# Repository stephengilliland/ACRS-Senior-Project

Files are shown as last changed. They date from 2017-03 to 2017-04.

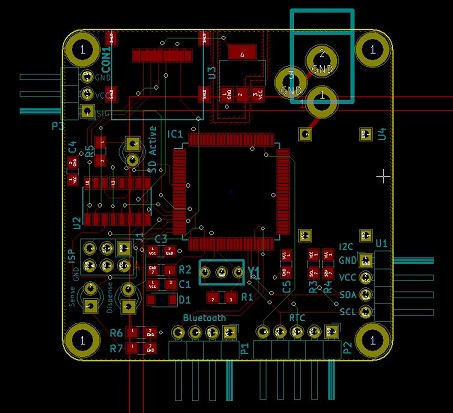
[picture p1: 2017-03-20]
Boards/SP1/BoardLayoutPIC.JPG

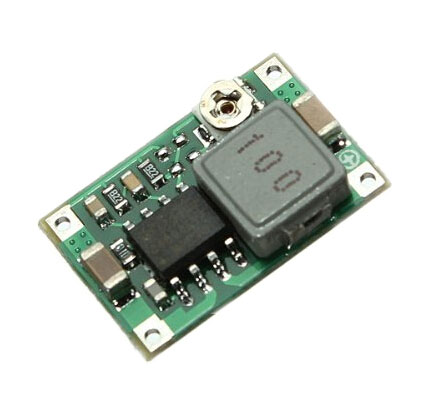
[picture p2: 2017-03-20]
Boards/SP1/Buck.jpg

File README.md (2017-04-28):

# Aquatic Chemical Regulation System (ACRS)

#### Group Members:
- Stephen Gilliland
- Nicholas Zugates
- George Tittnitch

## What is ACRS?
ACRS is a water chemical regulation system which uses various sensors connected via I2C bus to take measurements of chemical content, temperature, pH and turbidity. These readings are used in order to make adjustments to the balance of chemicals in the water. The system is interfaced to the user via an Android app. The readings aquired by the system are logged in a microSD card for recordkeeping purposes.

The main goal of the system is modularity; meaning any of our sensors connected to the controller I2C bus will be automatically recognized and read. The I2C bus is compatible with up to 127 slave devices.

## Hardware

The project utilizes multiple microprocessors, one of which acts as a I2C Master(Main Controller), the rest are attached to the sensors and act as Slave devices(Sensors). The master is a different processor due to the need of more program space. The other device's programs are minimal thus they do not need much space.

Device | MicroController Used | Program Space | SRAM
------------ | ------------- | ------- | ----- 
Master device | ATmega2560 | 256KB | 8KB
Slave devices | ATmega328 | 32KB | 2KB

## Software
The software for the main controller is an large part of ACRS due to the many functions of the diverse system and the number of sensors that can be used with it.  Some of the functions include: Reading sensors, app communication, timekeeping, data logging, and pump control. Due to the ability to customize these things from the app, the program is extensive.

The initial setup of the program initializes variables, outputs, and some of the devices hooked up to the controller. It also sets up the bluetooth parameters. It then searches for connected sensors by testing every possible I2C address (1 to 128, 0 is the controller) and saving the addresses of the devices connected into an array. The array is used to increment through all sensor’s addresses and get their values. This is done by requesting 2 bytes, the first is the sensor type and the second is the data from that sensor. The controller then saves the data into the correct variable based on what sensor was just read. This process is done for every sensor connected every time the program runs the read sensors function. 

The main loop of the program works in response to commands received from the smartphone app, these commands trigger specific actions in the controller such as: setting user settings or sending data to the app. The commands are sent as 1 character numbers and interpreted by the controller. There are 6 different commands the controller can receive from the app, they are as follows:

Set dispense mode: Automatic
Set dispense mode: Manual
Get Sensor readings
Dispense chemicals (if set to manual)
Change pool size
Change measurement interval

Changing the dispense mode to automatic simply changes the controller mode to dispense chemicals on it’s own when the readings are out of a preset tolerance. While when set to manual mode, the controller will not do anything until the user sends the command to do so.

A command to get new sensor readings makes the controller send the most recent measurements. As soon is this request is made, a string is sent over bluetooth containing the sensor values. The string is parsed and the values are displayed by the app. 

A dispense chemicals command causes the controller to make calculations based on the user entered pool size, chemical measurements, and desired chemical content. It then sends data to the dispensing controller which takes the necessary action in order to regulate the chemical content of the water. This command is only used if the dispensing setting is set to manual.

The last two commands simply set some preferences. Set pool size sets the size of the body of water being regulated, this is important due to the calculations that are done before dispensing chemicals being dependant on this data. The second preference is the test interval, this preference is the amount of time (in minutes) between each chemical test, because data is logged every time sensor readings are gathered; this also sets the data logging interval.

### The Controller
The device chosen for this for the main controller is the Atmega2560. The Atmega2560 is an 8-bit microcontroller that is well suited for the application. There are many reasons that this controller was the right one for the application: it’s an Arduino compatible processor, it has the serial peripherals needed to communicate to the necessary devices, and it has enough memory space to hold the large main program. 

Arduino compatibility is a very beneficial advantage due to the large amount of libraries and support that are available. Arduino also has a very convenient windows application for writing code, compilation, and uploading. The controller also needed a number of serial peripherals in order to communicate to the necessary devices such as: UART for communication to the bluetooth chip (RN-42) , I2C in order to get sensor values, and SPI to write to the microSD card for data logging purposes.

Because of the large number of devices the controller needed to interface with, a PCB was created which contains most of the needed devices and supporting circuitry. Included in the controller PCB are: the controller (Atmega2560), voltage regulators (3.3V and 5V), a microSD slot with supporting level-translators, and a 12DC input power jack.



### Data Logging
Data is logged to a microSD card using the SPI interface of the Atmega2560, with every set of values that are logged, a timestamp is also logged in order to give the user a record of data along with the date and time of the measurements.  An example of a data entry is as follows: 

“4/23/2017 20:23:59  pH=7.1  Temp=71.23  Chlorine=2.23  Trepidity=95”

### Sensors
The system begins with the three modular sensors collecting data from the water that is pulled through the system. These sensors each have a dedicated microcontroller that continually take measurements of the sensor values and send these values to the main controller upon request. The first sensor that the water passes over is the chlorine sensor. The design of the chlorine sensor is as followed. The base for the sensor is the TSL235R-LF light intensity to frequency converter. Its purpose is to collect light within the enclosure into which the water will be pumped. The light source is for the sensor is an LED that is mounted in a tube in order to direct the light through the water directly onto the sensors photodiode. The other key element in making this sensor work is the DPD chemical that is added through the top of the sensors container. This substance changes the color of the water to a purple hugh based off of the amount of free chlorine present in it. Now, once the DPD is added and the water changes color, the purple color blocks some of the light to the sensor. So, in order for this sensor to give relevant data, a correlation between the outputted frequency and the amount of chlorine needed to be made. This was done by utilizing the pool test kit described earlier. A sample of water was taken from the source and used in the pool test kit which would give a value between 1 and 5 parts per million. At the same time the same water source that the sample for the pool test kit was taken from was run through the sensor and the DPD was applied. Thus, the frequency that was outputted would correlate with the results given from the pool test kit (10KHZ = 2ppm for example).  
    
The pH sensor works similar to an amperometric sensor listed above. The main difference being that there is a plastic shield over the electrodes. The sensor compares the water passing over it to a controlled water sample stored in the sensor. The sensor outputs an analog signal that correlates to the pH level. This was done by using a sample of distilled water and adding pH packets  that were provided with the sensor. These packets, when mixed with distilled water, create a solution of known pH level. This was how the sensor calibration was performed. An example of this would be if a pH 4 packet was added whatever analog signal was outputted is the signal for a pH of 4. 

Finally, the turbidity sensor senses the clearness of the water. This a key test in water quality and even though it does not necessarily fit into the proof of concept, it is a perfect example of how the The A.C.R.S. is adaptable to multiple scenarios. The same goes for the temperature sensor, they are simply helpful for the user to have and show the future possibilities of the project. 

### The App
In order to give the user the most personal experience with the A.C.R.S. system, a user interface was developed in the form of an Android application.  This medium was chosen because in the current day and age it is most convenient for the everyday pool owner.  The app is easy to download, sync to the main system via Bluetooth, control, and monitor.

There are many programs on the market that can be used for Android application development. After experimentation with Android Studio, it was decided that another option was needed.  Further research concluded that MIT App Inventor 2 was the best option for the A.C.R.S. project purposes.

Upon further development the application could be altered and formatted for tablets and other personal devices.  As of now, the application is designed specifically for smartphones.

## Pictures/Videos
Put pictures and videos here.

## Resumes
- [Stephen Gilliland](./Resumes/SGilliland_Resume.pdf)
- [Nicholas Zugates](./Resumes/N_ZugatesResume.pdf)
- [George Tittnich](./Resumes/GeorgeTittnich_Resume.pdf )

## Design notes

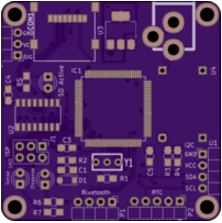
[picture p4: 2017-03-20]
Boards/SP1/Image.JPG

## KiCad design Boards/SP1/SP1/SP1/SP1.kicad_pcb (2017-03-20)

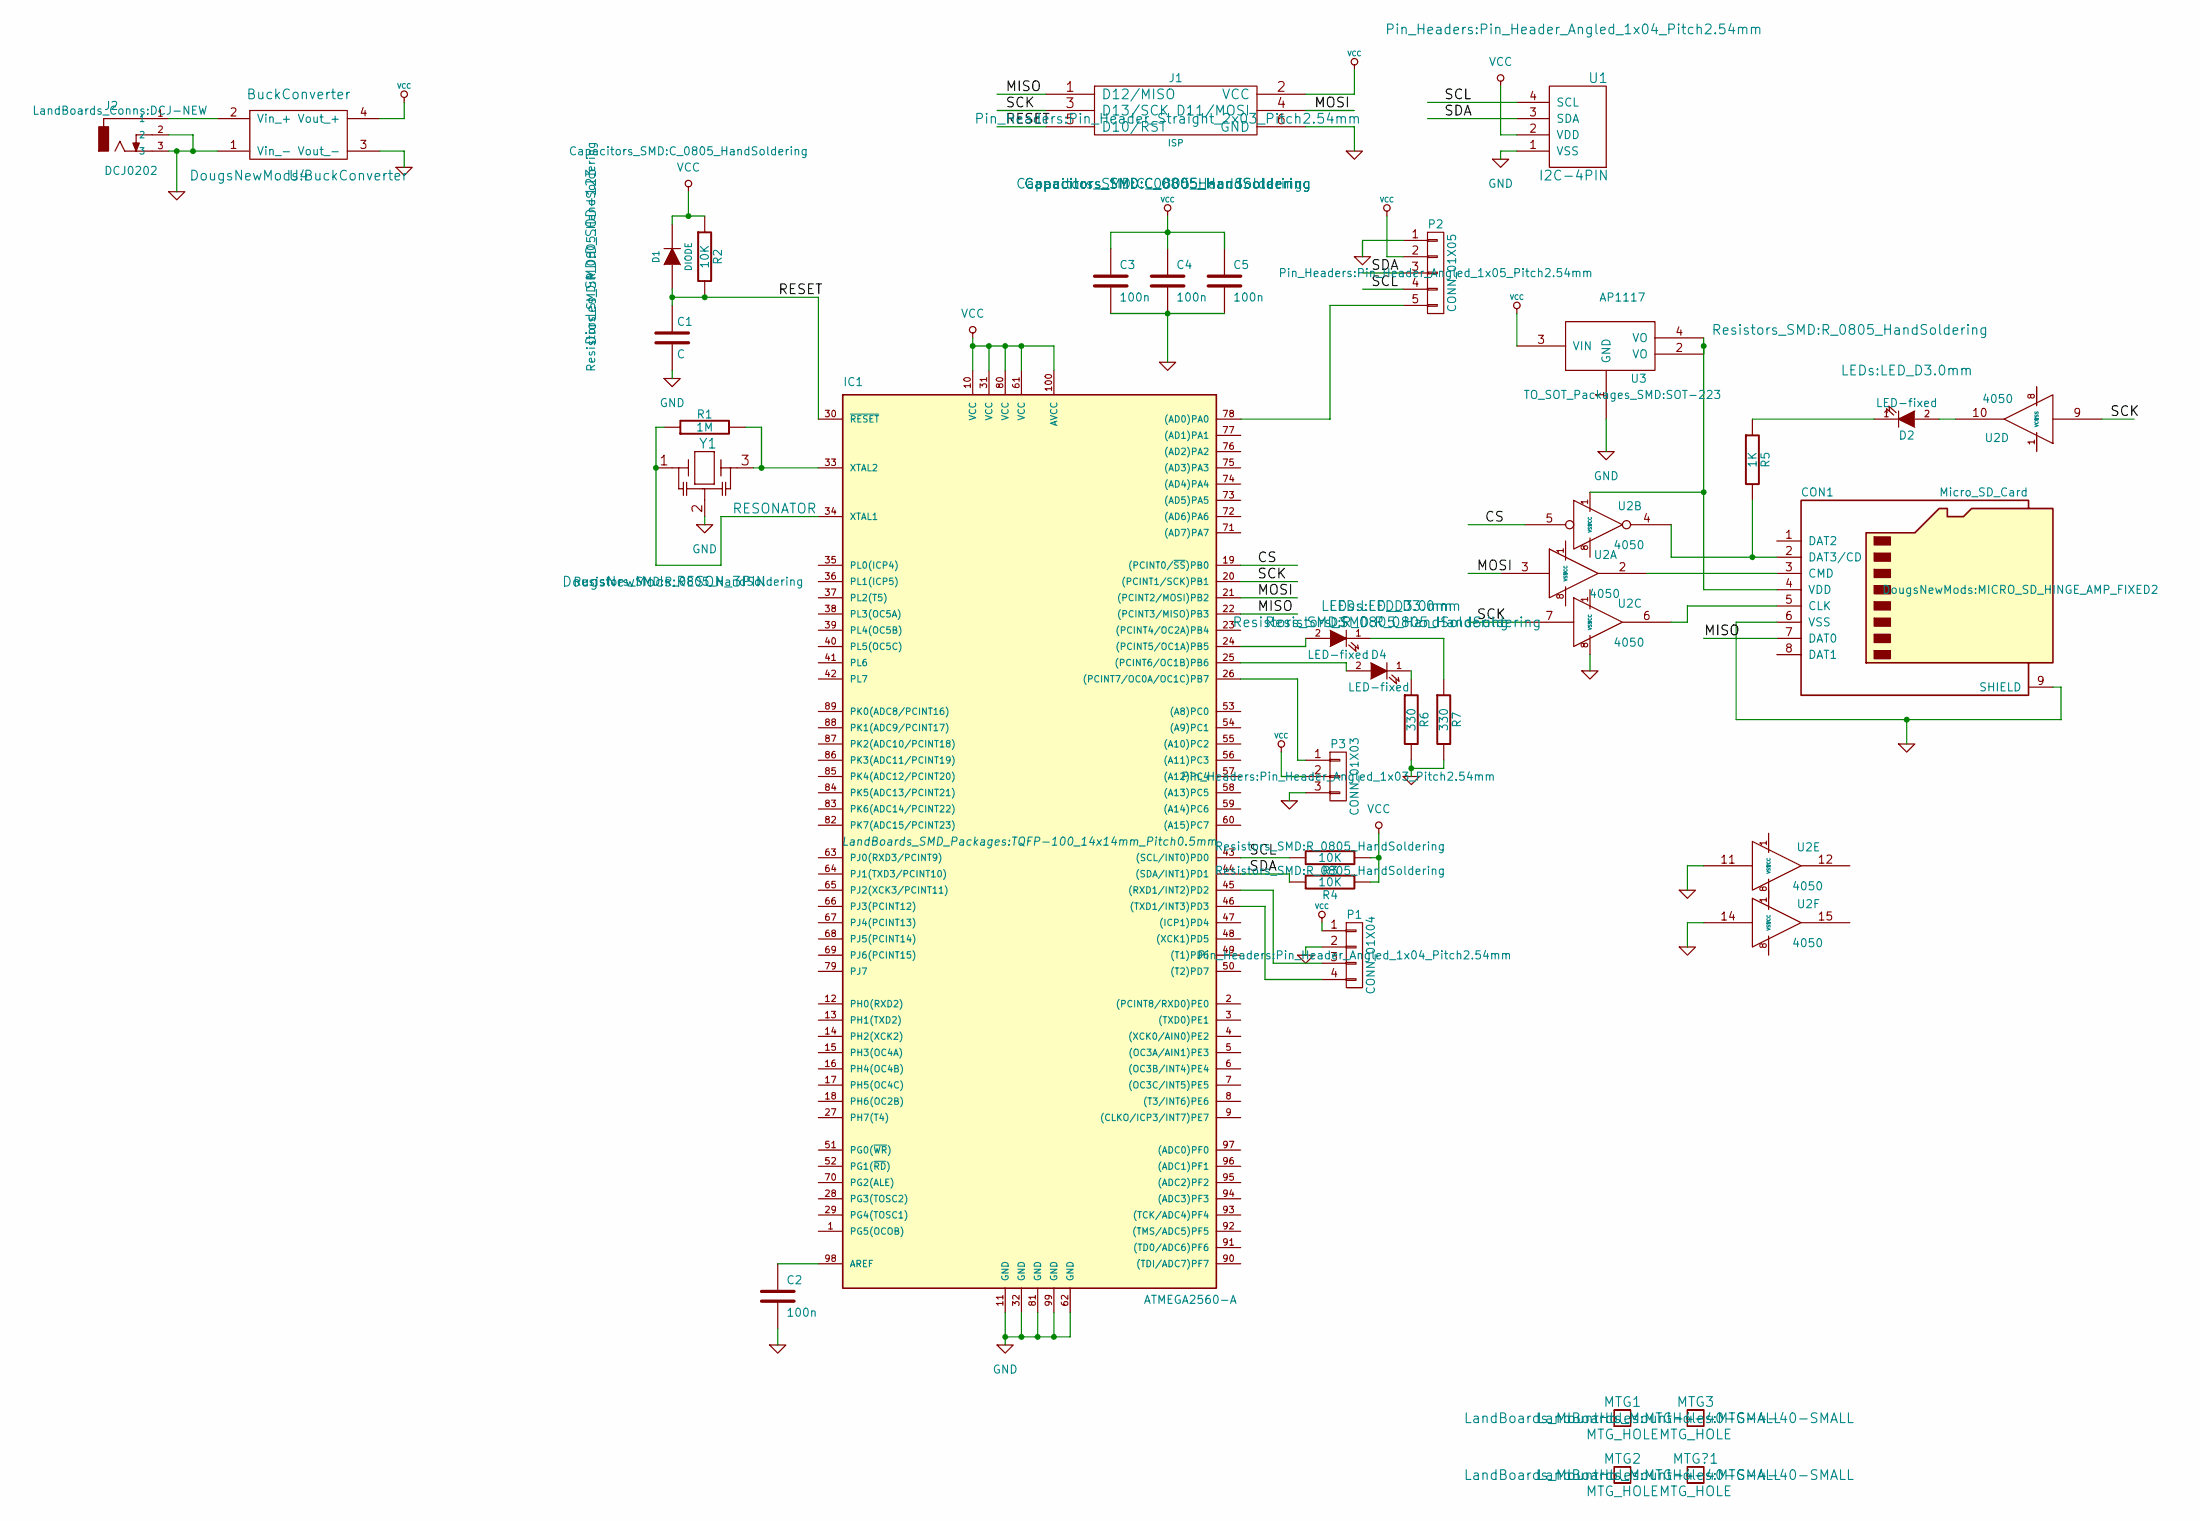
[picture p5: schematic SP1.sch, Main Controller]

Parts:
C1: C; C_0805_HandSoldering
C2: 100n
C3, C4, C5: 100n; C_0805_HandSoldering
CON1: Micro_SD_Card; MICRO_SD_HINGE_AMP_FIXED2
D1: DIODE; D_SOD-123
D2, D3, D4: LED-fixed; LED_D3.0mm
IC1: ATMEGA2560-A; TQFP-100_14x14mm_Pitch0.5mm
J1: ISP; Pin_Header_Straight_2x03_Pitch2.54mm
J2: DCJ0202; DCJ-NEW
MTG1, MTG2, MTG3: MTG_HOLE; MTG-4-40-SMALL
MTG?1: MTG_HOLE; MTG-4-40-SMALL
P1: CONN_01X04; Pin_Header_Angled_1x04_Pitch2.54mm
P2: CONN_01X05; Pin_Header_Angled_1x05_Pitch2.54mm
P3: CONN_01X03; Pin_Header_Angled_1x03_Pitch2.54mm
R1: 1M; R_0805_HandSoldering
R2, R3, R4: 10K; R_0805_HandSoldering
R5: 1K; R_0805_HandSoldering
R6, R7: 330; R_0805_HandSoldering
U1: I2C-4PIN; Pin_Header_Angled_1x04_Pitch2.54mm
U2: 4050; SOIC-16_3.9x9.9mm_Pitch1.27mm
U3: AP1117; SOT-223
U4: BuckConverter
Y1: RESONATOR; RESON_3PIN

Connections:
/CS: IC1.19 ((PCINT0/~SS~)PB0), U2.5
/MISO: CON1.7 (DAT0), IC1.22 ((PCINT3/MISO)PB3), J1.1 (D12/MISO)
/MOSI: IC1.21 ((PCINT2/MOSI)PB2), J1.4 (D11/MOSI), U2.3
/RESET: C1.1, D1.1 (A), IC1.30 (~RESET), J1.5 (D10/RST), R2.2
/SCK: IC1.20 ((PCINT1/SCK)PB1), J1.3 (D13/SCK), U2.7, U2.9
/SCL: IC1.43 ((SCL/INT0)PD0), P2.4, R3.2, U1.4 (SCL)
/SDA: IC1.44 ((SDA/INT1)PD1), P2.3, R4.2, U1.3 (SDA)
GND: C1.2, C2.2, C3.2, C4.2, C5.2, CON1.6 (VSS), CON1.9 (SHIELD), IC1.11 (GND), IC1.32 (GND), IC1.62 (GND), IC1.81 (GND), IC1.99 (GND), J1.6 (GND), J2.2, J2.3, P1.2, P2.1, P3.3, R6.2, R7.2, U1.1 (VSS), U2.8 (VSS), U2.11, U2.14, U3.1 (GND), U4.1 (Vin_-), U4.3 (Vout_-), Y1.2
unnamed: C2.1, IC1.98 (AREF)
unnamed: CON1.2 (DAT3/CD), R5.2, U2.4
unnamed: CON1.3 (CMD), U2.2
unnamed: CON1.4 (VDD), U2.1 (VCC), U3.2 (VO), U3.4 (VO)
unnamed: CON1.5 (CLK), U2.6
unnamed: D2.1 (K), R5.1
unnamed: D2.2 (A), U2.10
unnamed: D3.1 (K), R7.1
unnamed: D3.2 (A), IC1.24 ((PCINT5/OC1A)PB5)
unnamed: D4.1 (K), R6.1
unnamed: D4.2 (A), IC1.25 ((PCINT6/OC1B)PB6)
unnamed: IC1.26 ((PCINT7/OC0A/OC1C)PB7), P3.1
unnamed: IC1.33 (XTAL2), R1.2, Y1.3
unnamed: IC1.34 (XTAL1), R1.1, Y1.1
unnamed: IC1.45 ((RXD1/INT2)PD2), P1.3
unnamed: IC1.46 ((TXD1/INT3)PD3), P1.4
unnamed: IC1.78 ((AD0)PA0), P2.5
unnamed: J2.1, U4.2 (Vin_+)
VCC: C3.1, C4.1, C5.1, D1.2 (K), IC1.10 (VCC), IC1.31 (VCC), IC1.61 (VCC), IC1.80 (VCC), IC1.100 (AVCC), J1.2 (VCC), P1.1, P2.2, P3.2, R2.1, R3.1, R4.1, U1.2 (VDD), U3.3 (VIN), U4.4 (Vout_+)

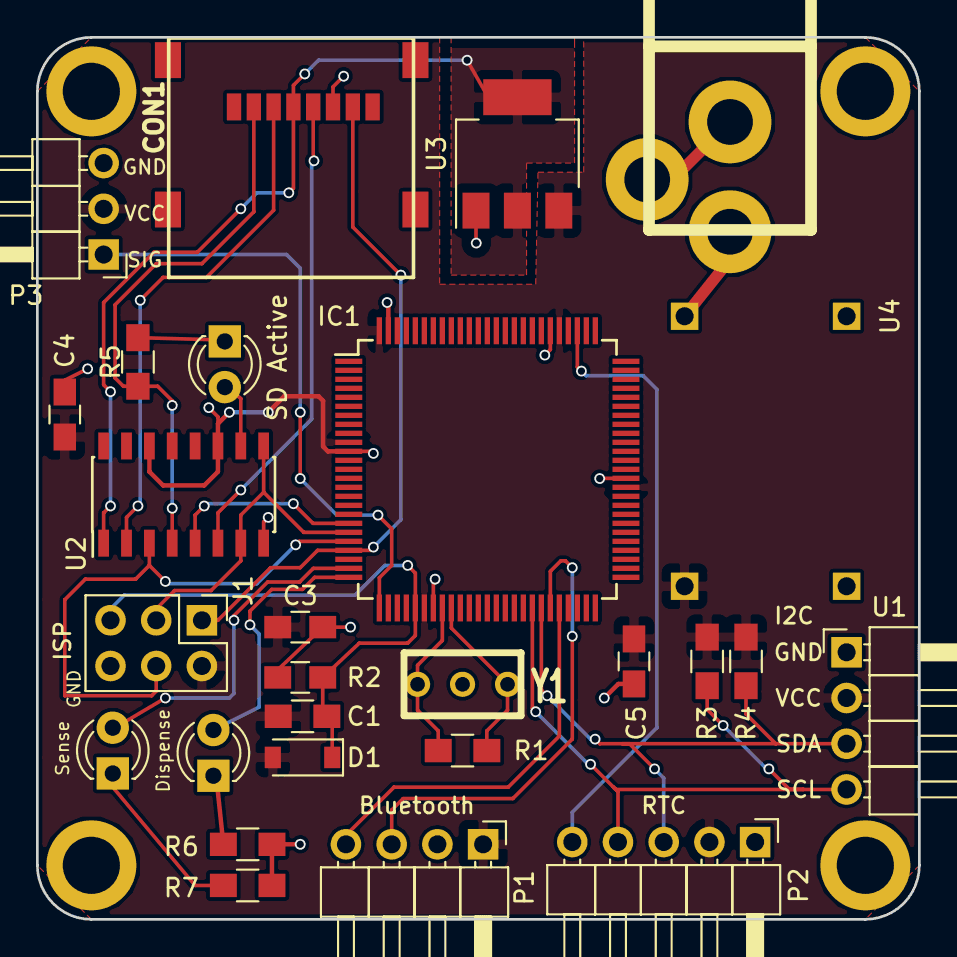
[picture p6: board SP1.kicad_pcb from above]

Board: 2 copper layers, 49.0 x 49.0 mm, 31 parts (0 on the bottom side), 26 nets.

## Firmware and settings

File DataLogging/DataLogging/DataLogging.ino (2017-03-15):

//Time stamped datalogger onto SD Card 
//@vmfoo - 7/19/2014

// change this to match your SD shield or module;
// Arduino Ethernet shield: pin 4
// Adafruit SD shields and modules: pin 10
// Sparkfun SD shield: pin 8
const int chipSelect = 4;    
//The RTC Library needs Wire
#include <Wire.h>
#include "RTClib.h"
RTC_DS1307 rtc;

#include <SPI.h>
#include "SD.h"
//The SDlibrary needs SPI

// Some SD Card code borrowed from Adafruit library examples
// Set up variables using the SD utility library functions:

File dataFile;
#define LOGFILE "datalog.txt"



void setup() {
  Serial.begin(19200); 
  //Initialize the Sensor
  Serial.println("Initializing datalogger with RTC version 1.0");
  
  
  Serial.println("Starting SDCard reader and card");
  pinMode(chipSelect, OUTPUT);
  pinMode(SS, OUTPUT);
  
  if (!SD.begin(chipSelect)) {
    Serial.println("SD Card initialization failed!");
    return;
  }
  
  Serial.println("Opening logfile for write.");
  // Open up the file we're going to log to!
  dataFile = SD.open(LOGFILE, FILE_WRITE);
  if (! dataFile) {
    Serial.println("error opening log file");
    // Wait forever since we cant write data
    while (1) ;
  }
  
  
  Serial.println("Starting Real Time Clock");
  #ifdef AVR
    Wire.begin();
  #else
    Wire1.begin(); // Shield I2C pins connect to alt I2C bus on Arduino Due
  #endif

  rtc.begin();
  //rtc.adjust(DateTime(F(__DATE__), F(__TIME__)));  //uncomment this once and upload. Then comment it out and upload again
  //This will set the time the first time you upload it and if you don't upload again with it commented out it will 
  //reset the clock to the time the code was compliled each time.
  
  if (! rtc.isrunning()) {  //code borrowed from adafruit example rtc code
    Serial.println("RTC is NOT running!");
    // following line sets the RTC to the date & time this sketch was compiled
    // This line sets the RTC with an explicit date & time, for example to set
    // January 21, 2014 at 3am you would call:
    // rtc.adjust(DateTime(2014, 1, 21, 3, 0, 0));
  }
  DateTime now = rtc.now();
  Serial.print("Unixtime: ");
  Serial.println(now.unixtime());
}

void loop(){
  char temp[6]; //2 int, 2 dec, 1 point, and \0
  char hum[6];  
  char msg[13];
  
  //get the temp/humid into chars to format
  ftoa(temp,20);
  ftoa(hum,55);
  
  //Compile a comma delimited string to send to the log
  sprintf(msg,"%s,%s",temp, hum);
  logThis(msg);  
  delay(3000); 
}

void logThis(char* logmessage){
  char message[120];
  DateTime now = rtc.now();
  long epoch = now.unixtime();
  int Year = now.year();
  int Month = now.month();
  int Day = now.day();
  int Hour = now.hour();
  int Minute = now.minute();
  int Second = now.second();
  sprintf(message, "%ld,%d/%d/%d %02d:%02d:%02d,%s",epoch,Year,Month,Day,Hour,Minute,Second,logmessage );
  //Write the entry to the log file and console
  dataFile.println(message);
  dataFile.flush();
  // print to the serial port too:
  Serial.println(message);
}

int ftoa(char *a, float f)  //translates floating point readings into strings
{
  int left=int(f);
  float decimal = f-left;
  int right = decimal *100; //2 decimal points
  if (right > 10) {  //if the decimal has two places already. Otherwise
    sprintf(a, "%d.%d",left,right);
  } else { 
    sprintf(a, "%d.0%d",left,right); //pad with a leading 0
  }
}

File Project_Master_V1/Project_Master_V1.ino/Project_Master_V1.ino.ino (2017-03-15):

const int chipSelect = 4; 
#include "TinyGPS.h"
#include<SoftwareSerial.h>
#include <Wire.h>
#include <SPI.h>
#include "SD.h"

#define RXPIN 8
#define TXPIN 7
#define LOGFILE "datalog.txt"

SoftwareSerial nss(RXPIN, TXPIN);
File dataFile;
TinyGPS gps;



int x, i, error, data, ndevices, counter, current, requestdata = 0;
float PH, AL, TR, TP, CH = 0;
unsigned long fix_age, Time, date;
unsigned long chars;
unsigned short sentences, failed_checksum;
char sensortype = '0';
int device[10];
bool done=false;

void setup() {
  // put your setup code here, to run once:
  nss.begin(9600);
  
  Wire.begin(); 
  
  Serial.begin(9600);
  while(!Serial){}
  Serial.print("$$$");
  delay(100);
  Serial.println("SM,0");
  delay(100);
  Serial.println("U,115200,N");
  delay(100);
  Serial.begin(9600);
  delay(100);

  Serial.println("Initializing datalogger");
  Serial.println("Starting SDCard");
  pinMode(chipSelect, OUTPUT);
  pinMode(SS, OUTPUT);
  
  if (!SD.begin(chipSelect)) {
    Serial.println("SD Card initialization failed!");
    return;
  }
  
  Serial.println("Opening logfile for write.");
  // Open up the file we're going to log to!
  dataFile = SD.open("datalog.txt", FILE_WRITE);
  if (! dataFile) {
    Serial.println("error opening log file");
    // Wait forever since we cant write data
    while (1) ;
  }
  dataFile.close();
  
  // Discover Devices
  for( i=1; i<128; i++ )
  {
    Wire.beginTransmission(i);
    error = Wire.endTransmission();
    if(error == 0)
    {
      ndevices ++;
    }
  }
  device[ndevices];
  
  // Discover Devices
  for(i=1; i<127; i++)
  {
    Wire.beginTransmission(i);
    error = Wire.endTransmission();
    if(error == 0)
    {
      device[counter] = i;
      counter++;
    }
  }
  Serial.print(ndevices);
  Serial.println(" Devices Found At Addresses: ");
  for( i=0;i<ndevices;i++ )
  {
    Serial.println(device[i]);  
  }
  Serial.println(" ");
}

void loop() {
  // put your main code here, to run repeatedly: 
   
  char tempS[7]; //2 int, 2 dec, 1 point, and \0
  char phS[7]; 
  char tripS[7];
  char chlorineS[7]; 
  char alkS[7];
  char msg[25];
  i = 0;
  counter = 0;
  
  while(done==false && counter<100)
  {
    while (nss.available())
    {
      int c = nss.read();
      if (gps.encode(c))
      {
        // process new gps info here
      }
    }  
    delay(10);
    // time in hhmmsscc, date in ddmmyy
    gps.get_datetime(&date, &Time, &fix_age);
    //Serial.println("Date/Time:");
    //Serial.println(Time);
    //Serial.println(date); 
    //Serial.println(counter); 
    counter++; 
  }
  done=true;

  // Get GPS Data
  while (nss.available())
  {
    int c = nss.read();
    if (gps.encode(c))
    {
      // process new gps info here
    }
  }  

  // Read Device Info
  for( i=0;i<ndevices;i++ )
  {
    Serial.print("Loop Number:  ");
    Serial.println(i);
    current = device[i];
    
    Wire.requestFrom(current, 1);    // request 1 byte from slave devices
    while (Wire.available())   // slave may send less than requested
    {
      sensortype = (char)Wire.read(); // receive a byte as character
    }

    Wire.requestFrom(current, 1);    // request 1 byte from slave devices
    while (Wire.available())   // slave may send less than requested
    {
      data = Wire.read(); // receive a byte as character
    }

    
    if(sensortype == 'P') // pH Sensor
    {
      PH = (float) data/10;
      Serial.print("Sensor Type = ");
      Serial.println("pH");
      Serial.print("pH = ");
      Serial.println(PH);
      Serial.println(" ");
    }
    if(sensortype == 'T') // Tribitiy Sensor
    {
      TR = data;
    }
    if(sensortype == 'A') // pH Sensor
    {
      AL = data;
      Serial.print("Sensor Type = ");
      Serial.println("Alkalenity");
      Serial.print("Alk = ");
      Serial.println(AL);
      Serial.println(" ");
    }
    if(sensortype == 'F') // pH Sensor
    {
      TP = data;
      Serial.print("Sensor Type = ");
      Serial.println("Temperature");
      Serial.print("temperature = ");
      Serial.println(TP);
      Serial.println(" ");
    }

   
  } 
  
   Serial.println("Done Looping");

   Serial.println(TP);
   Serial.println(PH);
   Serial.println(AL);
   Serial.println(CH);
   ftoa(tempS,TP);
   ftoa(phS,PH);
   ftoa(tripS,TR);
   ftoa(chlorineS,CH);
   
   sprintf(msg,"%s,%s,%s,%s",tempS, phS, tripS, chlorineS);
   //Serial.println(msg);
   logThis(msg); 
   delay(1000);
}

void logThis(char* logmessage){
  char message[75];
  gps.get_datetime(&date, &Time, &fix_age);
  //Serial.println(Time);
  //Serial.println(date);
  sprintf(message,"%lu,%lu,%s",date,Time,logmessage);
  //Write the entry to the log file and console
  File dataFile = SD.open("datalog.txt", FILE_WRITE);
  if (dataFile) {
    dataFile.println(message);
    dataFile.close();
    // print to the serial port too:
    Serial.println(message);
  }
  else
    Serial.println("Error opening log file");
}

int ftoa(char *a, float f)  //translates floating point readings into strings
{
  int left=int(f);
  float decimal = f-left;
  int right = decimal *100; //2 decimal points
  if (right > 10) {  //if the decimal has two places already. Otherwise
    sprintf(a, "%d.%d",left,right);
  } else { 
    sprintf(a, "%d.0%d",left,right); //pad with a leading 0
  }
}

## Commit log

2017-03-15 Replaced Repo
    [Daisychain_Adapter.kicad_pcb, Daisychain_Adapter.sch]
2017-03-20 Designed PC main Board
    [Daisychain_Adapter.kicad_pcb, Daisychain_Adapter.sch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]
2017-03-20 Added Board Picture
2017-03-20 Built I2C Daisychain Card
    [Daisychain_Adapter-B.Cu.gbr, Daisychain_Adapter-B.Mask.gbr, Daisychain_Adapter-B.SilkS.gbr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]
